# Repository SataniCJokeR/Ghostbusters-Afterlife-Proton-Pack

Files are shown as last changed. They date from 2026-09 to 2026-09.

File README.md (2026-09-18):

<p align="center">
  A WARNING!
</p>

Before you go any further, ask yourself one question:

**Why am I doing this?**

Why don’t I just look for a Proton Pack online and buy one? Surely there are ready-made Proton Packs out there. And if you factor in all the hours you’ll spend building your own, you’ll probably have made your money back the moment you click the “Buy Now” button.

You’re going to spend money you don’t have. You’re going to invest so much time that, when you finally emerge from your workshop, your family and friends will stare at you wide-eyed because they’ve **FORGOTTEN WHO YOU ARE**.

You’ll experience moments of sheer frustration: broken wires, dead components because you wired something up backwards *again*, and the inevitable realization that you forgot to slide the heat-shrink tubing onto the wire **before** soldering everything together.

Time. Money. Sanity.

**Are you really willing to risk it all?**

Give me one good reason why you should do this.

The answer is...

<br>
<br>
<br>
<br>
<br>
<br>
<br>
<br>
<br>
<br>

# THERE IS NO REASON. ONLY ZUUL!!!

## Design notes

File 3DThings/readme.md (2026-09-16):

<p align="center">
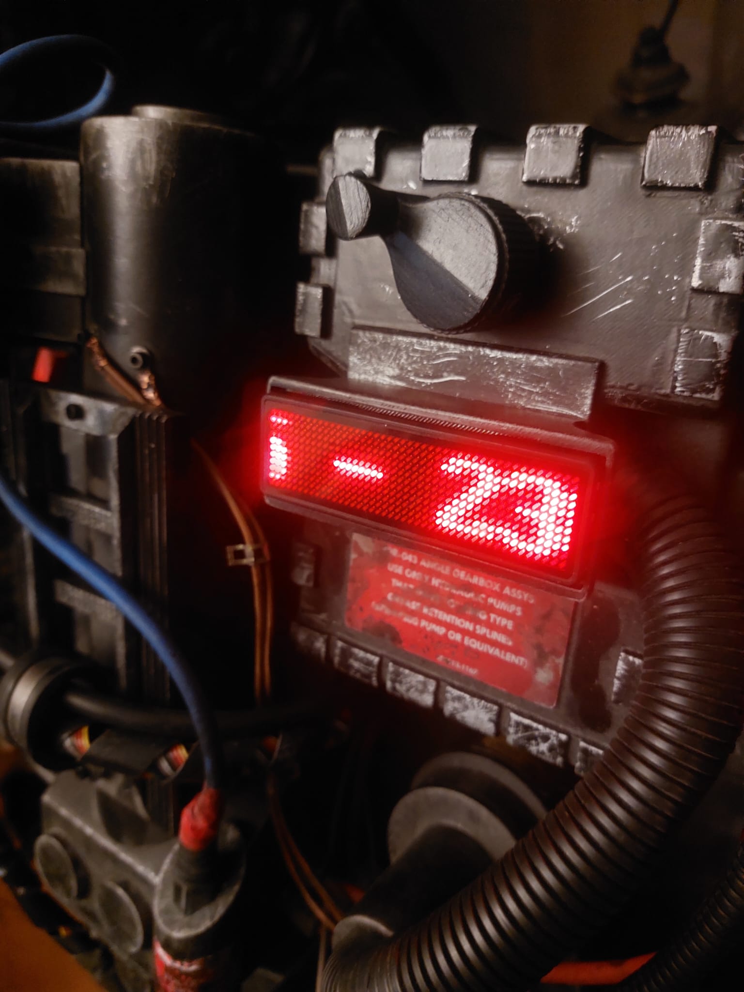
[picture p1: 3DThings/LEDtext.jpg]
scrolling text badge holder
  
</p>

https://a.co/d/08IrrD6H

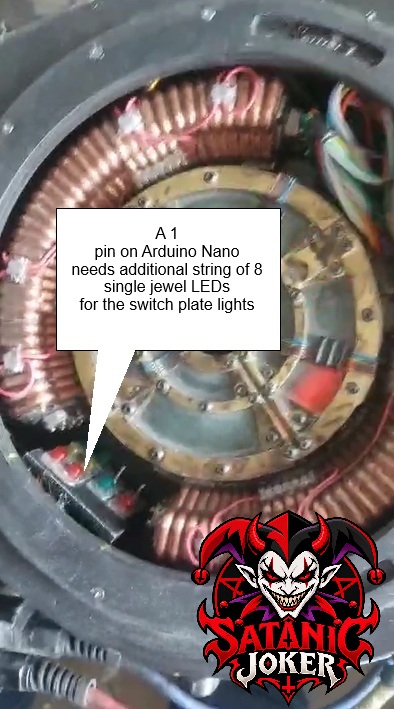
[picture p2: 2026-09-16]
images/workbench.jpg

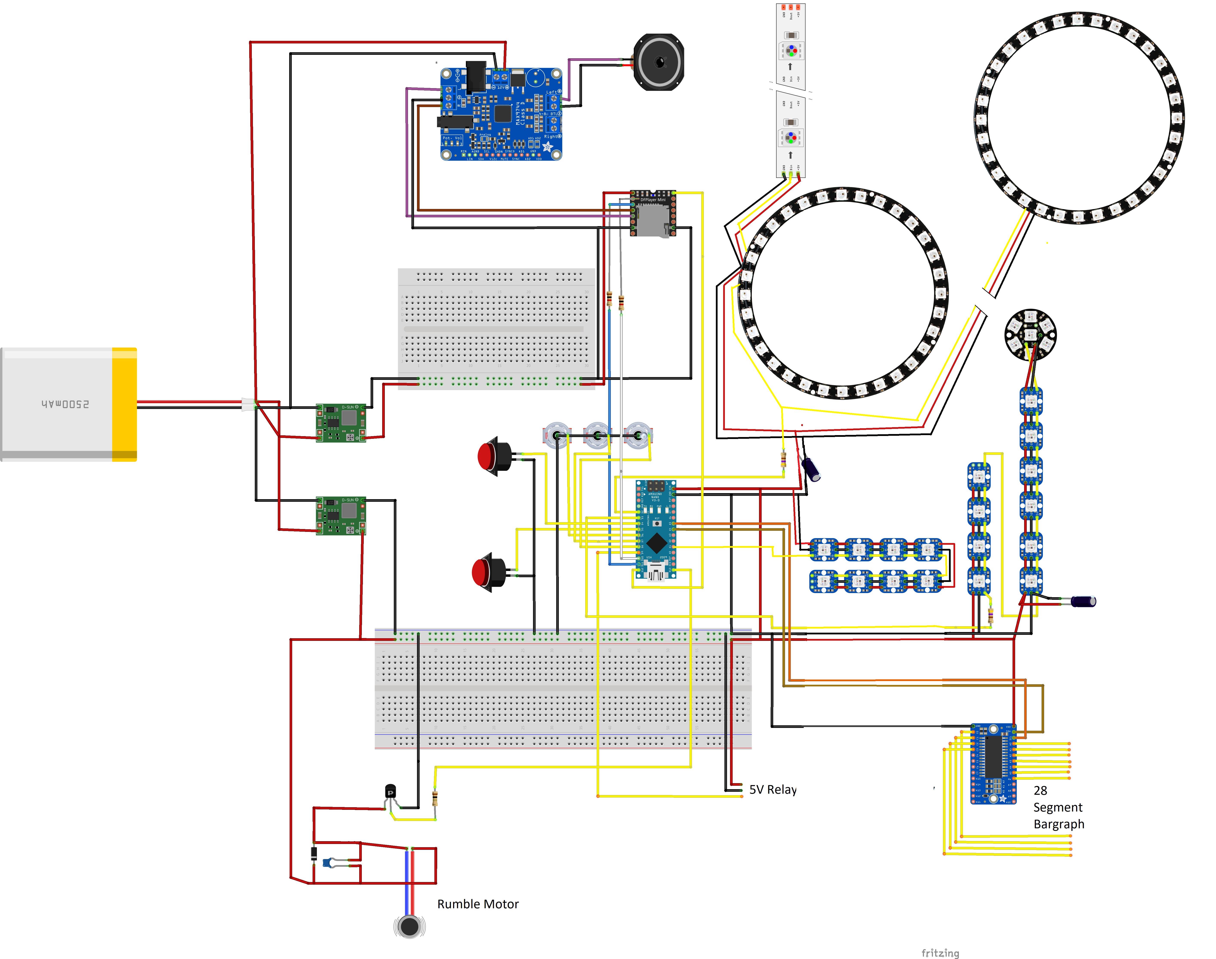
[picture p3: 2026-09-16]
Diagram/diagSJ2026.jpg

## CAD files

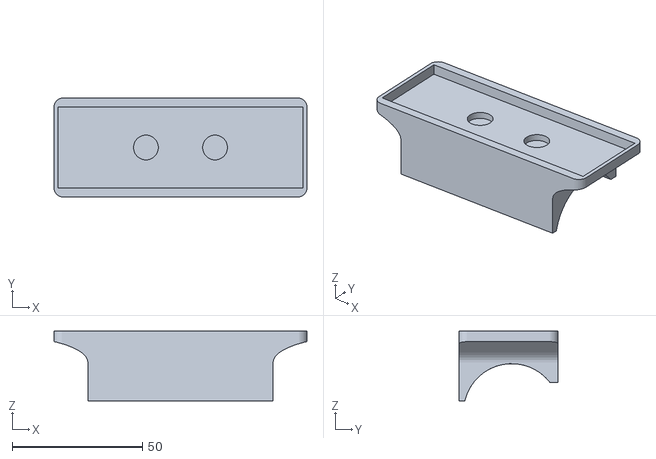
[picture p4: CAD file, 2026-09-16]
3DThings/LED_text_badge.stl
97.0 x 38.0 x 26.7

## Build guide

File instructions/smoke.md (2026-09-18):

# Building Your Own Proton Pack Smoke Machine

Want to add a smoke effect to your Ghostbusters Proton Pack? This guide covers the tools, materials, and smoke fluid for a compact smoke machine using a 5V air pump and a 1.8-ohm vaporizer. The diagram below shows the layout of my build.

## 1. Tools You'll Need

- Soldering iron
- Dremel with a grinding bit
- Scissors or utility knife
- Hot glue gun
- Wire stripper

## 2. Materials

- Solder
- High-temperature industrial hot glue
- Electrical tape
- **Heat-shrink tubing**
- Red and black electrical wires
- 6 mm PVC air hose
- 6 mm quick-connect fitting (optional, but convenient)
- 5V air pump
- 5V PC cooling fan
- 1.8-ohm vaporizer (Kanger T2)
- TalentCell power bank with a 12V output
- Suitable buck converter for the 5V pump and fan
- A separately regulated, appropriately rated power supply for the vaporizer
- Suitable connectors, switching and electrical protection

The quick-connect fitting makes it easier to detach the hose for servicing and refilling. Check whether your hose is specified by its inner or outer diameter before buying a fitting.

## 3. Wiring and Assembly Diagram

<p align="center">
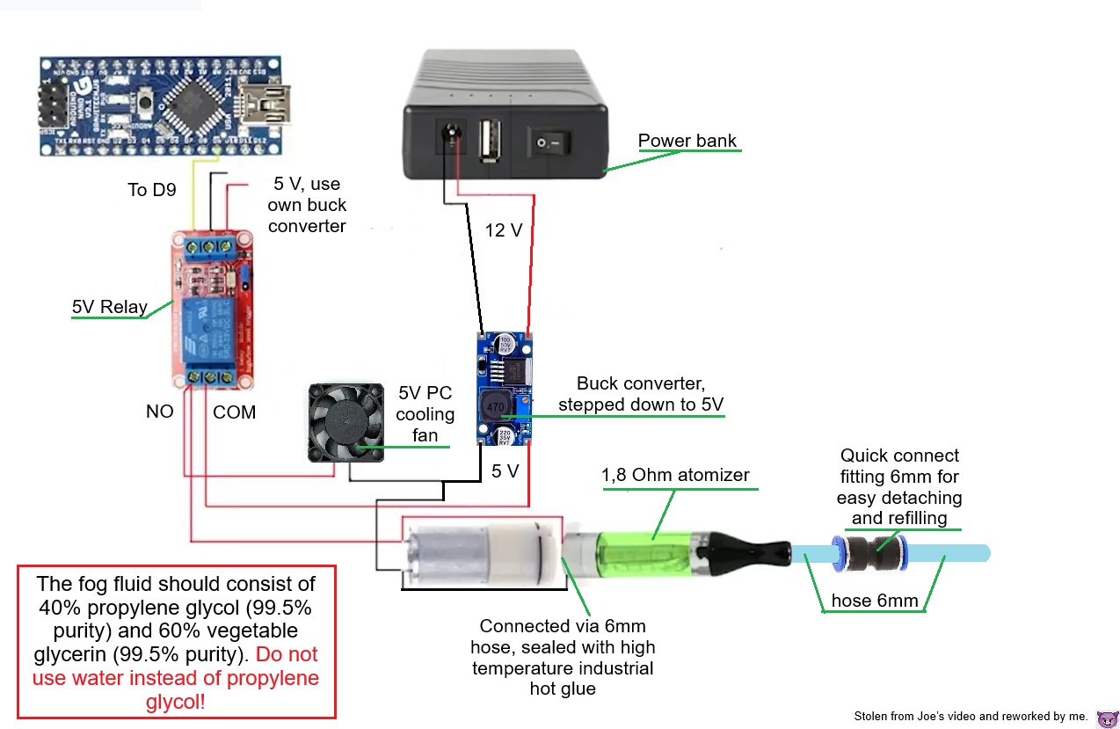
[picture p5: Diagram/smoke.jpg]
DIY smoke machine
  
</p>

*Diagram based on Joe's video and revised for my build.*

**Important electrical and heat precautions:** The 1.8-ohm vaporizer must not be connected directly to the TalentCell 12V output. Keep hot glue away from the coil and other heated surfaces. Use heat-shrink tubing to insulate soldered electrical joints, and use a suitable driver and protection for any higher-current load.

## 4. Smoke Fluid

The intended smoke fluid for this build consists of:

| Ingredient | Proportion | Purity |
| --- | ---: | ---: |
| Propylene glycol (PG) | 40% | 99.5% |
| Plant-based vegetable glycerin (VG) | 60% | 99.5% |

## 5. Before You Start Building

Check all component voltage and current ratings. Set and verify any adjustable converter's output before connecting its load. Keep the vaporizer upright and away from heat-sensitive parts; ensure the air outlet is not blocked and leaking fluid cannot reach electrical connections. The air hose must connect to the intended airflow path, not pressurize the liquid reservoir. Never operate the coil dry or unattended.

## 6. Recommended Video Tutorial

I highly recommend watching KamuiCosplay's YouTube tutorial featuring Svetlana before starting your build. Her demonstration is particularly useful for seeing how the components fit together.

Not only does she have a grrrreat German accent, her voice could probably raise the dead. Just kidding. Love you, Svetlana!

**Video:** (https://www.youtube.com/watch?v=uDISX8MMLak&t=381s)

If you want to SEE, how to wire this up, have a look at wholesomejoe´s video!

**Video:** (https://youtu.be/ciG3mJstMbo?si=-ihIuFimQip9ONlE)

---

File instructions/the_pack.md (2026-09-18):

# SataniC JokeR's Afterlife 2026 Proton Pack
<p align="center">
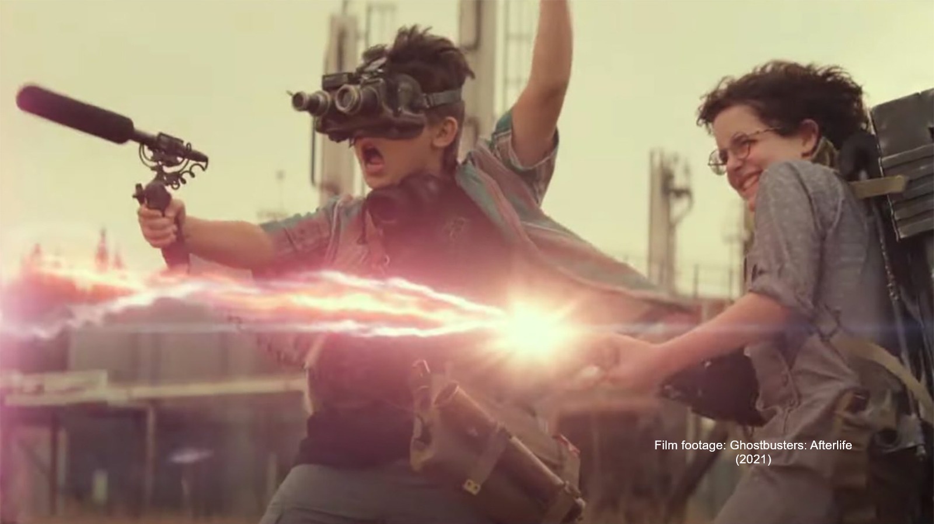
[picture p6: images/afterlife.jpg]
Afterlife 2021
  
</p>
 
Firmware, libraries & sound installation guide

**Project:** Ghostbusters Afterlife 2026 by SataniC JokeR / Acki  
**Controller:** Classic Arduino Nano (ATmega328P)

This guide covers installing the `SataniCJokeR_Afterlife_2026` Arduino firmware and its matching audio files, including the custom libraries, DFPlayer Mini microSD card, wiring reference, first startup, and troubleshooting.

> **Important:** The `.ino` file alone is not a complete installation. You also need the matching custom library files and pack sounds.

## 1. Before you begin

| Required item | Purpose |
| --- | --- |
| Classic Arduino Nano | Runs the firmware |
| DFPlayer Mini and microSD card | Play pack effects and optional music |
| USB data cable and Arduino IDE | Compile and upload the sketch |
| `SataniCJokeR_Afterlife_2026.ino` | Main firmware |
| Pack WAV files `0001.wav`–`0032.wav` | Original effects and prepared crossfade transitions |
| Custom `BGSequence` and `GBLEDPatterns` files | Project-specific bargraph and LED code |

## 2. Install Arduino IDE and select the board

1. Download and install the [Arduino IDE](https://www.arduino.cc/en/software).
2. Connect the Nano using a USB data cable. If necessary, install **Arduino AVR Boards** through **Tools → Board → Boards Manager**.
3. Select **Tools → Board → Arduino AVR Boards → Arduino Nano**, then **Tools → Processor → ATmega328P**.
4. Select the correct USB/COM port under **Tools → Port**. If an older Nano or compatible clone will not upload, try **ATmega328P (Old Bootloader)**.

## 3. Install the required libraries

The sketch includes six headers:

| Header / library | Installation method / role |
| --- | --- |
| `DFPlayerMini_Fast.h` | Install [DFPlayerMini_Fast](https://github.com/PowerBroker2/DFPlayerMini_Fast) through Arduino Library Manager; DFPlayer control. |
| `FastLED.h` | Install [FastLED](https://github.com/FastLED/FastLED) through Arduino Library Manager; addressable LEDs. |
| `Adafruit_NeoPixel.h` | Install [Adafruit NeoPixel](https://github.com/adafruit/Adafruit_NeoPixel) through Arduino Library Manager; LED strips. |
| `SoftwareSerial.h` | Provided by the Arduino AVR platform; normally no separate installation. |
| `BGSequence.h` + `BGSequence.cpp` | Matching project-specific files for the 28-segment bargraph. |
| `GBLEDPatterns.h` | Matching project-specific Proton Pack LED code. |

In Arduino IDE, open **Tools → Manage Libraries**, search for each third-party library by its exact name, and click **Install**. You can also install a library ZIP through **Sketch → Include Library → Add .ZIP Library**.

**Use the matching custom project files.** Unrelated libraries with similar names are not substitutes.

## 4. Arrange and upload the sketch

Keep the sketch and its matching custom source files together:

```text
SataniCJokeR_Afterlife_2026/
├── SataniCJokeR_Afterlife_2026.ino
├── BGSequence.h
├── BGSequence.cpp
└── GBLEDPatterns.h
```

1. Open `SataniCJokeR_Afterlife_2026.ino` in Arduino IDE.
2. Click **Verify**. Resolve any missing-library errors before uploading.
3. Confirm the Nano board, processor, and USB/COM port, then click **Upload**.

The firmware is installed on the Arduino Nano. **The audio files go on the DFPlayer's microSD card**, not in the `.ino` file or the Nano's flash memory.

## 5. Prepare the DFPlayer microSD card

1. Back up the card, then format a compatible microSD card as **FAT32**. A card of 32 GB or less is a practical starting point; avoid exFAT.
2. At the **root** of the card, create two folders with these exact names: `mp3` and `01`.
3. Copy all original and crossfade pack effects into `/mp3`, with four-digit WAV filenames from `0001.wav` through `0032.wav`.
4. Copy optional music into `/01`, with three-digit MP3 filenames such as `001.mp3`, `002.mp3`, and `003.mp3`.

```text
microSD card/
├── mp3/
│   ├── 0001.wav
│   ├── 0002.wav
│   ├── ...
│   └── 0032.wav
└── 01/
    ├── 001.mp3
    ├── 002.mp3
    └── ...
```

**Why is the WAV folder named `mp3`?** `mp3` is the DFPlayer's special folder name. It **does not** mean the pack WAV files should be converted to MP3. The sketch calls `playFromMP3Folder()` to address this folder.

Keep the original sounds and crossfades together:

- `0001.wav`–`0021.wav`: original pack sounds.
- `0022.wav`–`0032.wav`: prepared transition WAV files.
- `0032.wav`: the current complete Vent sequence, combining Vent, Post Vent, Boot After Vent, and Idle 3.
- `0029.wav`–`0031.wav`: reserve/pair-test transitions.

Keep the **supplied audio format and timing**. For replacement pack files, 16-bit PCM WAV at 44.1 kHz is a sensible target, but timing-sensitive replacements may also require firmware changes.

If the DFPlayer selects the wrong track, back up and reformat the card, then copy the numbered files in ascending order. Avoid duplicate numbers and hidden metadata files. Safely eject the card and switch off the DFPlayer before inserting or removing it.

## 6. Audio file reference

| Filename | Sound / transition |
| --- | --- |
| `0001.wav` | Power On |
| `0002.wav` | Boot |
| `0003.wav` | Pack Idle (Idle 1) |
| `0004.wav` / `0005.wav` / `0006.wav` | Ramp 1 On / Idle / Down |
| `0007.wav` / `0008.wav` / `0009.wav` | Ramp 2 On / Idle / Down |
| `0010.wav` / `0011.wav` / `0012.wav` | Fire / Fire Loop / Fire Tail |
| `0013.wav` / `0014.wav` / `0015.wav` | Alarm / Vent / Off |
| `0016.wav` / `0017.wav` / `0018.wav` | Boot After Vent / Error / Error Off |
| `0019.wav` / `0020.wav` / `0021.wav` | Post Vent / Standby Loop / Fire 2 Intro |
| `0022.wav` / `0023.wav` | Power On → Standby / Boot → Idle 1 |
| `0024.wav` / `0025.wav` | Ramp 1 On → Idle 2 / Ramp 1 Down → Idle 1 |
| `0026.wav` / `0027.wav` | Ramp 2 On → Idle 3 / Ramp 2 Down → Idle 2 |
| `0028.wav` | Fire Tail → Idle 3 |
| `0029.wav`–`0031.wav` | Reserve crossfade pair files |
| `0032.wav` | Complete Vent chain |

## 7. Arduino Nano pin reference

| Pin | Connection |
| --- | --- |
| D2 | 55 WS2812 LEDs: Cyclotron 0–39, Power Cell 40–54 |
| D3 | 17 WS2812 LEDs: Vent, Wand, and Jewel |
| D4 / D5 | Fire Button 1 / Fire Button 2 (active LOW) |
| D6 / D7 / D8 | Wand / Pack / Music Mode switches (HIGH = ON) |
| D9 | Venting relay control output |
| D10 (Arduino RX) | Connect to DFPlayer TX |
| D11 (Arduino TX) | Connect to DFPlayer RX |
| D12 | DFPlayer BUSY, LOW while playing |
| D13 | Rumble control output |
| A1 | Separate 8-LED status chain |

Use a stable power supply rated for the LEDs and audio hardware, and connect all grounds together. Do not power the full LED installation through the Nano regulator. **D9 and D13 are control pins:** use suitable drivers for relays, motors, or other higher-current loads.

## 8. Initial operation and test

1. Start with **D6/D7/D8 OFF** and both Fire buttons released. On a real power-up, Power On plays once, followed by the Standby loop (`0020.wav`).
2. Switch **D7 ON**. Boot plays; afterward, Idle 1 should repeat `0003.wav`. Let it play long enough to confirm the loop.
3. Switch **D6 ON**. Ramp 1 On leads to Idle 2, which repeats `0005.wav`.
4. Switch **D8 ON**. Ramp 2 On leads to Idle 3, which repeats `0008.wav`.
5. Test **D4 and D5** firing. Each has its own intro. Holding Fire for ten seconds enters the alarm phase; releasing afterward starts Venting.
6. While a ramp is running, reverse **D6** (Ramp 1) or **D8** (Ramp 2) to test the immediate opposite ramp without waiting for Idle.
7. Switch **D7 OFF** to begin PowerDown. Once all controls have been observed OFF, switch D7 back ON during PowerDown to test immediate reboot.

`SataniCJokeR_Afterlife_2026` also allows **D8 OFF during Post Vent (`0019.wav`) or Boot After Vent (`0016.wav`)** to start Ramp 2 Down without an Error.

<p align="center">
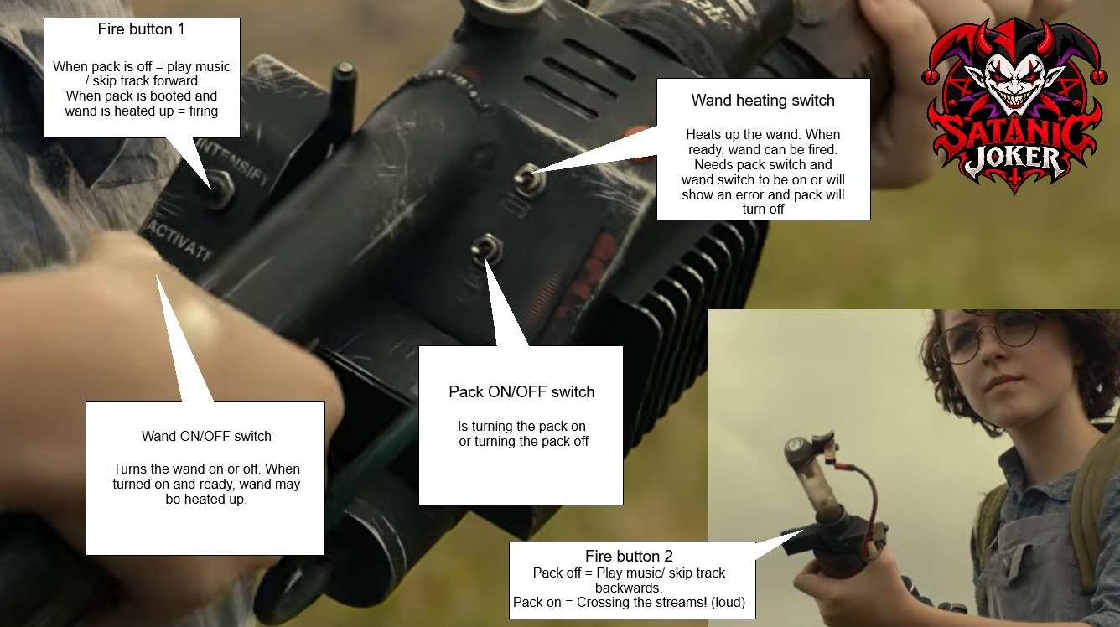
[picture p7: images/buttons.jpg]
wand buttons
  
</p>
<p align="center">
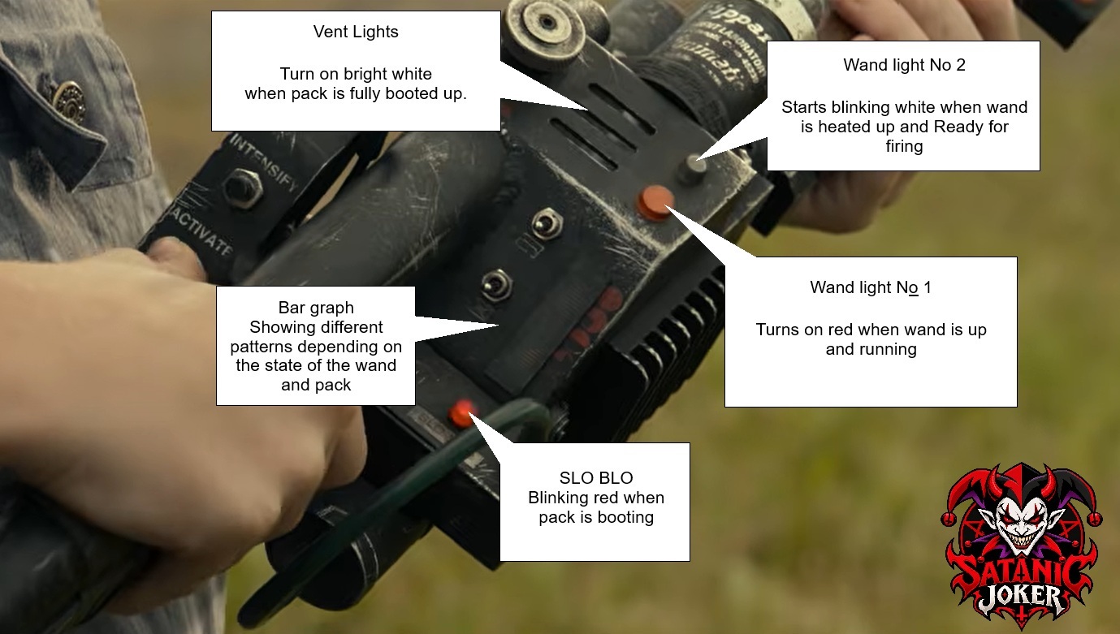
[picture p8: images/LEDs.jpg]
wand switches
  
</p>

## 9. Troubleshooting

| Symptom | What to check |
| --- | --- |
| Missing `BGSequence.h` / `GBLEDPatterns.h` | Add the matching project-specific `.h` / `.cpp` files to the sketch folder. |
| Missing `DFPlayerMini_Fast.h` | Install DFPlayerMini_Fast; a different DFPlayer library is not a drop-in replacement. |
| Compilation succeeds; upload fails | Check USB data cable, COM port, Nano processor, and Old Bootloader option. |
| No audio | Check DFPlayer power, common ground, TX/RX wiring, speaker or amplifier, microSD card, and `/mp3` folder. |
| Wrong numbered track | Check folder and filename format, duplicate files, and file-copy order. |
| Idle plays once, then goes silent | Check D12 → BUSY, audio file presence, and correct firmware. |
| LEDs not responding | Check data pins, power supply, ground, and matching custom LED files. |

## 10. Final checklist

- [ ] Arduino IDE and Nano board package installed.
- [ ] DFPlayerMini_Fast, FastLED, and Adafruit NeoPixel installed.
- [ ] Matching `BGSequence.h`, `BGSequence.cpp`, and `GBLEDPatterns.h` present.
- [ ] `SataniCJokeR_Afterlife_2026` sketch verifies and uploads.
- [ ] microSD card formatted as FAT32.
- [ ] `/mp3` contains `0001.wav`–`0032.wav`.
- [ ] Optional music stored in `/01` as `001.mp3`, `002.mp3`, etc.
- [ ] D12 correctly connected to DFPlayer BUSY.
- [ ] Power and ground connections checked.
- [ ] Power On, Idle loops, firing, reversals, and Venting tested.

## Reference links and acknowledgements

**Software and documentation**

- [Arduino IDE](https://www.arduino.cc/en/software)
- [Arduino: Installing a library](https://docs.arduino.cc/software/ide-v2/tutorials/ide-v2-installing-a-library/)
- [DFPlayerMini_Fast](https://github.com/PowerBroker2/DFPlayerMini_Fast)
- [FastLED](https://github.com/FastLED/FastLED)
- [Adafruit NeoPixel](https://github.com/adafruit/Adafruit_NeoPixel)
- [DFRobot DFPlayer Mini documentation](https://drive.google.com/drive/folders/1ZK_mpFw1HRCU08vdL3db9uLpBYtM99ma))

**Proton Pack build resources**

- [3D-printable Proton Pack by Q](https://github.com/mr-kiou/q-pack/tree/MK4). Including the wand pop nechanism. Thank you, Mr. Q!
- [Workbench 3D files by LeBazarDuQ](https://www.etsy.com/de/shop/LeBazarDuQ?ref=l2-about-shopname&from_page=listing) (available for purchase).
- [Decals for the pack and the wand for self printing on adhesive film](https://drive.google.com/drive/folders/1ZK_mpFw1HRCU08vdL3db9uLpBYtM99ma). I used silver DIN A4 adhesive film sheets

If you run into problems while building your Proton Pack, check out [WholesomeJoe's older YouTube build-video playlist](https://www.youtube.com/playlist?list=PLhiyMZuH8tBOwNic7S3f29nyA3fqoB7SK). He walks through the build step by step, although his version uses MikeS11's code.

Without him, I would never have been able to create what you see here today. **Thank you, Joe! :\***

<p align="center">
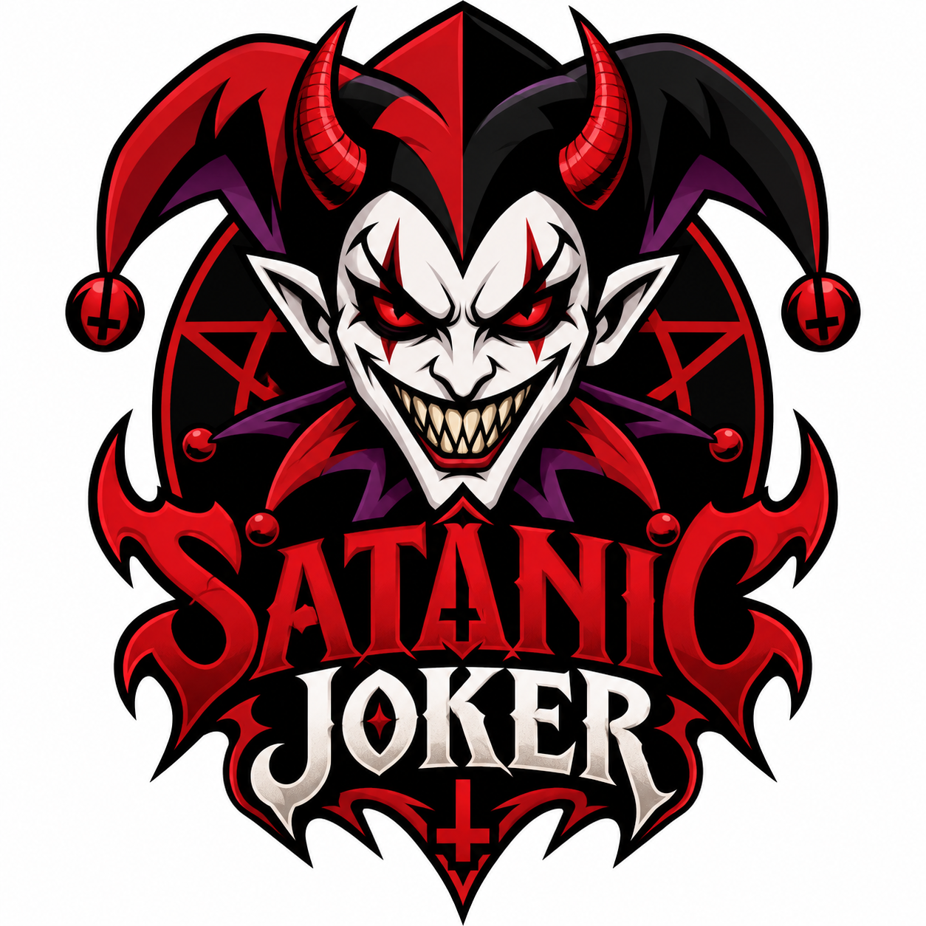
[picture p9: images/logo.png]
SataniC JokeR logo
  
</p>

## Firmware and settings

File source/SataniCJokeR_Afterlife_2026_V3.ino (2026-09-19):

/****************************************************************************************
   SataniC JokeR´s Ghostbusters Afterlife 2026
   Arduino Nano 

   Hardware:
     D2  = 55 WS2812/NeoPixel LEDs: Cyclotron 0..39, PowerCell 40..54
     D3  = 17 WS2812/NeoPixel LEDs: Vent 0..3, SloBlo 4, WandVent 5, Theme 6,
                                    White1 7, White2 8, OrangeHat 9, Jewel 10..16
     D4  = Fire Button 1 (active LOW)
     D5  = Fire Button 2 (active LOW)
     D6  = Wand switch (HIGH = ON, same electrical behavior as before)
     D7  = Pack switch (HIGH = ON, same electrical behavior as before)
     D8  = Music Mode switch (HIGH = ON, same electrical behavior as before)
     D9  = Venting relay output
     D10 = SoftwareSerial RX  <- DFPlayer TX
     D11 = SoftwareSerial TX  -> DFPlayer RX
     D12 = DFPlayer BUSY (LOW = playing, HIGH = finished/idle)
     D13 = Rumble
     A1  = 8 WS2812 status LEDs

   Audio is kept strictly separated !!!!!!:
     Pack sounds: WAV files only in the /mp3 folder
                  /mp3/0001.wav ... /mp3/0032.wav
     Music:       MP3 files only in the /01 folder
                  /01/001.mp3, /01/002.mp3, ...

   IMPORTANT NOTES ABOUT WAV / MP3:
     - Pack sounds are WAV files in this project.
     - Music tracks are MP3 files in this project.
     - The DFPlayer addresses files by folder and track number, NOT by file
       extension. Therefore the library command playFromMP3Folder() is still
       used for pack sounds. It refers to the special /mp3 folder and does not
       define the actual audio file format.
     - The /mp3 folder contains the original WAV files 0001.wav through
       0021.wav plus the crossfade files 0022.wav through 0032.wav.
     - The /01 folder should contain only music files such as 001.mp3,
       002.mp3, and so on.
     - PCM, 16-bit, 44.1 kHz is recommended for the pack WAV files.
       Remove metadata/tags where possible.

   Logical pack sound IDs -> actual WAV file:
     000 Power On             -> /mp3/0001.wav
     001 Boot                 -> /mp3/0002.wav
     002 Pack Idle            -> /mp3/0003.wav
     003 Ramp 1 On            -> /mp3/0004.wav
     004 Ramp 1 Idle          -> /mp3/0005.wav
     005 Ramp 1 Down          -> /mp3/0006.wav
     006 Ramp 2 On            -> /mp3/0007.wav
     007 Ramp 2 Idle          -> /mp3/0008.wav
     008 Ramp 2 Down          -> /mp3/0009.wav
     009 Fire                 -> /mp3/0010.wav
     010 Fire Loop            -> /mp3/0011.wav
     011 Fire Tail            -> /mp3/0012.wav
     012 Pack Alarm           -> /mp3/0013.wav
     013 Vent                 -> /mp3/0014.wav
     014 Off                  -> /mp3/0015.wav
     015 Boot Up After Vent   -> /mp3/0016.wav
     016 Error                -> /mp3/0017.wav
     017 Error Off            -> /mp3/0018.wav
     018 Post Vent            -> /mp3/0019.wav
     019 Standby Loop         -> /mp3/0020.wav
     020 Fire 2 Intro         -> /mp3/0021.wav
     021 XF PowerOn->Standby  -> /mp3/0022.wav
     022 XF Boot->Idle1       -> /mp3/0023.wav
     023 XF Ramp1On->Idle2    -> /mp3/0024.wav
     024 XF Ramp1Down->Idle1  -> /mp3/0025.wav
     025 XF Ramp2On->Idle3    -> /mp3/0026.wav
     026 XF Ramp2Down->Idle2  -> /mp3/0027.wav
     027 XF FireTail->Idle3   -> /mp3/0028.wav
     028 XF Vent->PostVent    -> /mp3/0029.wav (reserve / pair test)
     029 XF PostVent->After   -> /mp3/0030.wav (reserve / pair test)
     030 XF AfterVent->Idle3  -> /mp3/0031.wav (reserve / pair test)
     031 XF complete Vent chain -> /mp3/0032.wav (used by the current sketch)

   Music files:
     /01/001.mp3, /01/002.mp3, /01/003.mp3, ...

****************************************************************************************/

#include <BGSequence.h>
#include "SoftwareSerial.h"
#include <DFPlayerMini_Fast.h>
#include "FastLED.h"
#include <Adafruit_NeoPixel.h>
#include "GBLEDPatterns.h"

/************************* Hardware / Libraries *************************/
BGSequence BarGraph;

enum BarGraphSequences { START, ACTIVE, FIRE1, FIRE2, BGVENT };
BarGraphSequences BGMODE;

SoftwareSerial mySoftwareSerial(10, 11); // RX, TX
DFPlayerMini_Fast myDFPlayer;

const uint8_t STARTWAND_SWITCH = 6;
const uint8_t STARTPACK_SWITCH = 7;
const uint8_t MUSIC_SWITCH     = 8;
const uint8_t FIRE_BUTTON      = 4;
const uint8_t FIRE_BUTTON2     = 5;
const uint8_t VENTING          = 9;
const uint8_t ISPLAYING_OUT    = 12;
const uint8_t RUMBLE           = 13;

const int NeoPixelLEDCount1 = 55;
const int NeoPixelLEDCount2 = 17;
const int AuxLEDCount        = 8;

#define NEO_WAND 3
#define AUX_LED_PIN A1

Adafruit_NeoPixel wandLights(NeoPixelLEDCount2, NEO_WAND, NEO_GRB + NEO_KHZ800);
Adafruit_NeoPixel auxLights(AuxLEDCount, AUX_LED_PIN, NEO_GRB + NEO_KHZ800);

void PackLEDsComplete();
NeoPatterns PackLEDs(NeoPixelLEDCount1, 2, NEO_GRB + NEO_KHZ800, &PackLEDsComplete);

// Keep the legacy Theme ID for compatibility with GBLEDPatterns / fireStrobe.
enum PackTheme { MOVIE, STATIS, SLIME, MESON, CHRISTMAS };
PackTheme THEME = STATIS;

/************************* D3 LED Indices *************************/
const uint8_t ventStart    = 0;
const uint8_t ventEnd      = 3;
const uint8_t SloBloLED    = 4;
const uint8_t WandVentLED  = 5;
const uint8_t ThemeLED     = 6;
const uint8_t WhiteLED1    = 7;
const uint8_t WhiteLED2    = 8;
const uint8_t OrangeHatLED = 9;
const uint8_t GunLEDStart  = 10;
const uint8_t GunLEDEnd    = 16;

/************************* Audio *************************/
// Logical IDs 000..031. The /mp3 track number is addressed internally as ID + 1.
enum PackSound : uint8_t {
  SND_POWER_ON = 0,
  SND_BOOT,
  SND_PACK_IDLE,
  SND_RAMP1_ON,
  SND_RAMP1_IDLE,
  SND_RAMP1_DOWN,
  SND_RAMP2_ON,
  SND_RAMP2_IDLE,
  SND_RAMP2_DOWN,
  SND_FIRE,
  SND_FIRE_LOOP,
  SND_FIRE_TAIL,
  SND_PACK_ALARM,
  SND_VENT,
  SND_OFF,
  SND_BOOT_AFTER_VENT,
  SND_ERROR,
  SND_ERROR_OFF,
  SND_POST_VENT,
  SND_STANDBY_LOOP,
  SND_FIRE2_INTRO,
  SND_XF_POWERON_STANDBY,    // 0022.wav
  SND_XF_BOOT_IDLE1,         // 0023.wav
  SND_XF_RAMP1ON_IDLE2,      // 0024.wav
  SND_XF_RAMP1DOWN_IDLE1,    // 0025.wav
  SND_XF_RAMP2ON_IDLE3,      // 0026.wav
  SND_XF_RAMP2DOWN_IDLE2,    // 0027.wav
  SND_XF_FIRETAIL_IDLE3,     // 0028.wav
  SND_XF_VENT_POSTVENT,      // 0029.wav, reserve
  SND_XF_POSTVENT_AFTERVENT, // 0030.wav, reserve
  SND_XF_AFTERVENT_IDLE3,    // 0031.wav, reserve
  SND_XF_VENT_CHAIN          // 0032.wav
};

const uint8_t MUSIC_FOLDER = 1;
uint8_t currentMusicTrack = 1;
bool musicHasStarted = false;

// BUSY tracking for one-shot sounds whose end triggers a state transition.
bool packSoundLooping = false;
// Tracks whether the DFPlayer is currently in Repeat mode, independent of system state.
// This matters because music also uses Repeat. This allows stopRepeat() to be sent only
// when it is actually required.
bool dfRepeatActive = false;
bool packSoundBusySeen = false;
unsigned long packSoundStartedAt = 0;
// 0023.wav (Boot -> Idle1) is almost 39 seconds long. Therefore the BUSY
// fallback for combined files must be significantly longer than 30 seconds.
const unsigned long SOUND_END_FALLBACK_MS = 60000UL;

// A crossfade file contains the transition AND one complete first pass
// of the following Idle sound. Only after the combined file truly ends
// is the normal repeating loop of the target Idle sound started.
bool combinedTailActive = false;
PackSound combinedTailLoopSound = SND_STANDBY_LOOP;

// FIX17: General loop watchdog for Standby and Idle 1/2/3.
// On the real hardware, after a one-shot sound/crossfade the DFPlayer may
// start the loop track but occasionally fail to accept the immediately following
// startRepeat() command. D12/BUSY is therefore monitored in the stable
// loop states and the expected loop is restarted when necessary.
bool packLoopBusySeen = false;
unsigned long packLoopIdleSince = 0;
PackSound watchedPackLoopSound = SND_STANDBY_LOOP;
const unsigned long PACK_LOOP_IDLE_RESTART_MS = 250UL;
const unsigned long PACK_LOOP_START_TIMEOUT_MS = 1200UL;

/************************* State Machine *************************/
enum SystemState : uint8_t {
  ST_STANDBY,
  ST_MUSIC,
  ST_BOOT,
  ST_IDLE1,
  ST_RAMP1_ON,
  ST_IDLE2,
  ST_RAMP1_DOWN,
  ST_RAMP2_ON,
  ST_IDLE3,
  ST_RAMP2_DOWN,
  ST_FIRING,
  ST_WARNING,
  ST_FASTWARNING,
  ST_FIRE_TAIL,
  ST_VENT_PREDELAY,
  ST_VENT_ACTIVE,
  ST_POST_VENT_SOUND,
  ST_AFTER_VENT,
  ST_ERROR_STANDBY,
  ST_POWERDOWN,
  ST_WAIT_ALL_OFF
};

SystemState state = ST_STANDBY;
unsigned long stateStartedAt = 0;

// While the one-shot Power On sound is still playing, no Standby inputs are processed.
bool powerOnSoundPending = true;

bool firstSuccessfulBootDone = false;
unsigned long activeBootDurationMs = 15000UL;

// PowerDown: Error exit (017) or normal exit (014).
bool powerDownIsError = false;
SystemState powerDownSourceState = ST_STANDBY; // remembers which state initiated PowerDown
// FIX17: For EVERY PowerDown, remember whether during the running shutdown
// all controls have actually been observed OFF/released at least once.
// After that, D7 may immediately interrupt the running PowerDown and start Boot.
bool powerDownAllOffSeen = false;
const unsigned long POWERDOWN_DURATION_MS = 10000UL;
float powerDownStartRPM = 300.0f;

/************************* Timing *************************/
const unsigned long FIRING_WARNING_MS = 5000UL;
const unsigned long FIRING_ALARM_MS   = 10000UL;
const unsigned long VENT_PREDELAY_MS  = 2000UL;

// Source sound lengths used to determine when the state logic changes from
// the transition state to the target state. These values match the files
// that were actually uploaded for the crossfade package.
// Note: the uploaded 0001.wav is 2.905 seconds long.
const unsigned long LEN_0001_MS = 2905UL;
const unsigned long LEN_0002_MS = 17661UL;
const unsigned long LEN_0003_MS = 21495UL;
const unsigned long LEN_0004_MS = 1723UL;
const unsigned long LEN_0005_MS = 20868UL;
const unsigned long LEN_0006_MS = 1985UL;
const unsigned long LEN_0007_MS = 1642UL;
const unsigned long LEN_0008_MS = 14029UL;
const unsigned long LEN_0009_MS = 1879UL;
const unsigned long LEN_0010_MS = 14410UL;
const unsigned long LEN_0011_MS = 7890UL;
const unsigned long LEN_0012_MS = 3678UL;
const unsigned long LEN_0013_MS = 7570UL;
const unsigned long LEN_0014_MS = 5521UL;
const unsigned long LEN_0015_MS = 11910UL;
const unsigned long LEN_0016_MS = 1689UL;
const unsigned long LEN_0017_MS = 467UL;
const unsigned long LEN_0018_MS = 11890UL;
const unsigned long LEN_0019_MS = 1968UL;
const unsigned long LEN_0020_MS = 8403UL;
const unsigned long LEN_0021_MS = 14250UL;

// FIX15 crossfade lengths, for documentation/audio alignment only.
const unsigned long XF_0001_0020_MS = 400UL;
const unsigned long XF_0002_0003_MS = 400UL;
const unsigned long XF_0004_0005_MS = 345UL;
const unsigned long XF_0006_0003_MS = 397UL;
const unsigned long XF_0007_0008_MS = 328UL;
const unsigned long XF_0009_0005_MS = 376UL;
const unsigned long XF_0012_0008_MS = 400UL;
const unsigned long XF_0014_0019_MS = 394UL;
const unsigned long XF_0019_0016_MS = 338UL;
const unsigned long XF_0016_0008_MS = 338UL;

/************************* Input Debouncing *************************/
struct DebouncedInput {
  uint8_t pin;
  bool stable;
  bool lastRaw;
  unsigned long rawChangedAt;
  bool rose;
  bool fell;
};

DebouncedInput inD4 = { FIRE_BUTTON, HIGH, HIGH, 0, false, false };
DebouncedInput inD5 = { FIRE_BUTTON2, HIGH, HIGH, 0, false, false };
DebouncedInput inD6 = { STARTWAND_SWITCH, LOW, LOW, 0, false, false };
DebouncedInput inD7 = { STARTPACK_SWITCH, LOW, LOW, 0, false, false };
DebouncedInput inD8 = { MUSIC_SWITCH, LOW, LOW, 0, false, false };

const unsigned long DEBOUNCE_MS = 25UL;

void initDebouncedInput(DebouncedInput &in) {
  bool raw = digitalRead(in.pin);
  in.stable = raw;
  in.lastRaw = raw;
  in.rawChangedAt = millis();
  in.rose = false;
  in.fell = false;
}

void updateDebouncedInput(DebouncedInput &in, unsigned long now) {
  in.rose = false;
  in.fell = false;

  bool raw = digitalRead(in.pin);
  if (raw != in.lastRaw) {
    in.lastRaw = raw;
    in.rawChangedAt = now;
  }

  if ((now - in.rawChangedAt) >= DEBOUNCE_MS && in.stable != raw) {
    bool oldStable = in.stable;
    in.stable = raw;
    in.rose = (!oldStable && in.stable);
    in.fell = (oldStable && !in.stable);
  }
}

bool fire1Pressed() { return inD4.stable == LOW; }
bool fire2Pressed() { return inD5.stable == LOW; }
bool anyFirePressed() { return fire1Pressed() || fire2Pressed(); }
bool wandSwitchOn() { return inD6.stable == HIGH; }
bool packSwitchOn() { return inD7.stable == HIGH; }
bool musicSwitchOn() { return inD8.stable == HIGH; }

bool allControlsOff() {
  return !wandSwitchOn() && !packSwitchOn() && !musicSwitchOn() &&
         !fire1Pressed() && !fire2Pressed();
}

/************************* Manual Cyclotron *************************/
uint8_t ringHead = 0;
unsigned long lastRingStepMicros = 0;
float currentManualRPM = 300.0f;

// 40 LEDs: interval_us = 60.000.000 / (RPM * 40) = 1.500.000 / RPM
unsigned long rpmToStepMicros(float rpm) {
  if (rpm < 1.0f) rpm = 1.0f;
  return (unsigned long)(1500000.0f / rpm);
}
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
void loop() {
  unsigned long now = millis();

  updateDebouncedInput(inD4, now);
  updateDebouncedInput(inD5, now);
  updateDebouncedInput(inD6, now);
  updateDebouncedInput(inD7, now);
  updateDebouncedInput(inD8, now);

  /********************* State Logic *********************/
  switch (state) {
    case ST_STANDBY:
      // On a real power-up, 0022.wav plays: 0001 -> crossfade -> 0020.
      // Inputs remain locked until the nominal end of the uploaded 0001 section.
      // After that, the 0020 section of the combined file may continue playing.
      if (powerOnSoundPending) {
        if ((now - packSoundStartedAt) >= LEN_0001_MS) {
          powerOnSoundPending = false;
        }
        break;
      }

      // Priority order: switch errors first, D7 starts Boot,
      // Fire buttons control music. Any new state interrupts 0022 immediately.
      if (wandSwitchOn() || musicSwitchOn()) {
        enterStandbyError();
      } else if (packSwitchOn()) {
        enterBoot();
      } else if (inD4.fell) {
        musicHasStarted = false;
        selectNextMusicTrack();
        enterMusicVisuals();
      } else if (inD5.fell) {
        musicHasStarted = false;
        selectPreviousMusicTrack();
        enterMusicVisuals();
      } else {
        servicePackLoopWatchdog(now, SND_STANDBY_LOOP);
      }
      break;

    case ST_MUSIC:
      if (wandSwitchOn() || musicSwitchOn()) {
        enterStandbyError();
      } else if (packSwitchOn()) {
        enterBoot(); // playPackSound safely ends Music Repeat
      } else if (inD4.fell) {
        selectNextMusicTrack();
      } else if (inD5.fell) {
        selectPreviousMusicTrack();
      }
      break;

    case ST_BOOT: {
      // 0023.wav contains 0002 -> crossfade -> 0003. Fire D4/D5 remain
      // intentionally ignored during Boot. After the real 0002 duration, only
      // state/animation change to Idle 1; the combined WAV keeps playing.
      if (!packSwitchOn()) {
        startPowerDown(false); // 0015 Off
      } else if (wandSwitchOn() || musicSwitchOn()) {
        startPowerDown(true);  // 0018 Error Off
      } else if ((now - stateStartedAt) >= LEN_0002_MS) {
        firstSuccessfulBootDone = true;
        enterIdle1KeepAudio();
      }
      break;
    }

    case ST_IDLE1:
      if (!packSwitchOn()) {
        startPowerDown(false);
      } else if (musicSwitchOn()) {
        startPowerDown(true);
      } else if (wandSwitchOn()) {
        enterRamp1On();
      } else if (fire1Pressed() || fire2Pressed()) {
        startPowerDown(true);
      } else {
        servicePackLoopWatchdog(now, SND_PACK_IDLE);
      }
      break;

    case ST_RAMP1_ON:
      // 0024.wav = 0004 -> crossfade -> 0005.
      // FIX18: D6 may be switched OFF again while Ramp 1 On is still running.
      // Immediately start the opposite direction 0006 -> 0003, with no Error/Idle wait.
      if (!packSwitchOn()) {
        startPowerDown(false);
      } else if (!wandSwitchOn()) {
        enterRamp1Down();
      } else if (musicSwitchOn() || anyFirePressed()) {
        startPowerDown(true);
      } else if ((now - stateStartedAt) >= LEN_0004_MS) {
        enterIdle2KeepAudio();
      }
      break;

    case ST_IDLE2:
      if (!packSwitchOn()) {
        startPowerDown(false);
      } else if (fire1Pressed() || fire2Pressed()) {
        startPowerDown(true);
      } else if (!wandSwitchOn()) {
        enterRamp1Down();
      } else if (musicSwitchOn()) {
        enterRamp2On();
      } else {
        servicePackLoopWatchdog(now, SND_RAMP1_IDLE);
      }
      break;

    case ST_RAMP1_DOWN:
      // 0025.wav = 0006 -> crossfade -> 0003.
      // FIX18: D6 may be switched ON again while Ramp 1 Down is still running.
      // Immediately start the opposite direction 0004 -> 0005, with no Error/Idle wait.
      if (!packSwitchOn()) {
        startPowerDown(false);
      } else if (wandSwitchOn()) {
        enterRamp1On();
      } else if (musicSwitchOn() || anyFirePressed()) {
        startPowerDown(true);
      } else if ((now - stateStartedAt) >= LEN_0006_MS) {
        enterIdle1KeepAudio();
      }
      break;

    case ST_RAMP2_ON:
      // 0026.wav = 0007 -> crossfade -> 0008.
      // FIX18: D8 OFF immediately reverses direction while Ramp 2 On is still running.
      // D6 must remain ON for Ramp 2.
      if (!packSwitchOn()) {
        startPowerDown(false);
      } else if (!wandSwitchOn()) {
        startPowerDown(true);
      } else if (!musicSwitchOn()) {
        enterRamp2Down();
      } else if (anyFirePressed()) {
        startPowerDown(true);
      } else if ((now - stateStartedAt) >= LEN_0007_MS) {
        enterIdle3KeepAudio();
      }
      break;

    case ST_IDLE3:
      if (!packSwitchOn()) {
        startPowerDown(false);
      } else if (!wandSwitchOn()) {
        startPowerDown(true);
      } else if (!musicSwitchOn()) {
        enterRamp2Down();
      } else if (fire1Pressed() || fire2Pressed()) {
        enterFiring();
      } else {
        servicePackLoopWatchdog(now, SND_RAMP2_IDLE);
      }
      break;

    case ST_RAMP2_DOWN:
      // 0027.wav = 0009 -> crossfade -> 0005.
      // FIX18: D8 ON immediately reverses direction while Ramp 2 Down is still running.
      // D6 must remain ON for Ramp 2.
      if (!packSwitchOn()) {
        startPowerDown(false);
      } else if (!wandSwitchOn()) {
        startPowerDown(true);
      } else if (musicSwitchOn()) {
        enterRamp2On();
      } else if (anyFirePressed()) {
        startPowerDown(true);
      } else if ((now - stateStartedAt) >= LEN_0009_MS) {
        enterIdle2KeepAudio();
      }
      break;

    case ST_FIRING:
    case ST_WARNING: {
      if (handleActiveAbortSwitches()) break;

      unsigned long firingElapsed = now - stateStartedAt;

      // Play 0010 (D4) or 0021 (D5) completely, then 0011 Fire Loop
      // as long as FASTWARNING has not yet been reached.
      if (!fireIntroFinished && packSoundFinished()) {
        fireIntroFinished = true;
        loopPackSound(SND_FIRE_LOOP);
      }

      // The 10-second threshold has priority over button release in the same loop cycle.
      if (firingElapsed >= FIRING_ALARM_MS) {
        playPackSound(SND_PACK_ALARM);
        setState(ST_FASTWARNING);
      } else if (!anyFirePressed()) {
        enterFireTail();
      } else if (state == ST_FIRING && firingElapsed >= FIRING_WARNING_MS) {
        // Important: preserve total firing time. Do NOT reset stateStartedAt.
        state = ST_WARNING;
      }
      break;
    }

    case ST_FASTWARNING:
      if (handleActiveAbortSwitches()) break;
      if (!anyFirePressed()) {
        enterVentPreDelay();
      }
      break;

    case ST_FIRE_TAIL:
      if (handleActiveAbortSwitches()) break;
      // 0028.wav = 0012 -> crossfade -> 0008. The Fire buttons themselves remain
      // ignored during the actual 0012 section.
      if ((now - stateStartedAt) >= LEN_0012_MS) {
        enterIdle3KeepAudio();
      }
      break;

    case ST_VENT_PREDELAY:
      if (handleActiveAbortSwitches()) break;
      if ((now - stateStartedAt) >= VENT_PREDELAY_MS) {
        enterVentActive();
      }
      break;

    case ST_VENT_ACTIVE:
      if (handleActiveAbortSwitches()) break;
      // The 0014 section of 0032 ends after approximately 5.521 seconds total.
      // Since ST_VENT_ACTIVE begins after 2 seconds, 3.521 seconds remain here.
      if ((now - stateStartedAt) >= (LEN_0014_MS - VENT_PREDELAY_MS)) {
        enterPostVentSoundKeepAudio();
      }
      break;

    case ST_POST_VENT_SOUND:
      // 0032 keeps playing. FIX19: From the start of 0019, D8 may already
      // be switched OFF to immediately start Ramp 2 Down, without Error
      // and without waiting for 0016 / Idle 3.
      if (!packSwitchOn()) {
        startPowerDown(false);
      } else if (!wandSwitchOn()) {
        startPowerDown(true);
      } else if (!musicSwitchOn()) {
        enterRamp2Down();
      } else if ((now - stateStartedAt) >= LEN_0019_MS) {
        // If D8 remains ON, change only the state; 0032 keeps playing
        // into the 0016 section without sending a new DFPlayer command.
        enterAfterVentKeepAudio();
      }
      break;

    case ST_AFTER_VENT:
      // Special rule: D8 OFF during 0016 -> 0009 Ramp 2 Down -> Idle 2.
      if (!packSwitchOn()) {
        startPowerDown(false);
      } else if (!wandSwitchOn()) {
        startPowerDown(true);
      } else if (!musicSwitchOn()) {
        enterRamp2Down();
      } else if ((now - stateStartedAt) >= LEN_0016_MS) {
        // The 0008 section is already part of 0032 and keeps playing.
        enterIdle3KeepAudio();
      }
      // D4/D5 are intentionally ignored during the 0016 section.
      break;
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

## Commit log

2026-09-16 Enhance README with installation and setup details
    Expanded the README to include detailed installation and setup instructions for the Ghostbusters Afterlife Proton Pack project, including required components, wiring, audio file references, and troub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
2026-09-16 Add images for switches and LEDs
    Added images of switches and LEDs to README.
2026-09-16 Rename buttons and switches.jpg to buttons.jpg
2026-09-16 Add image to readme for LED text display
2026-09-18 Revise smoke machine instructions and video links
    Updated video links and added a recommendation for wiring guidance.
